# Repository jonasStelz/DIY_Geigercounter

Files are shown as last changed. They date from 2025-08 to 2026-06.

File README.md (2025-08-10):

# ESP32-S3 Geiger Counter PCB

A custom-designed **battery-powered** Geiger counter board created in **KiCad**, featuring an **ESP32-S3-WROOM-1** module, an LCD display, and a high-voltage section for driving a Geiger–Müller tube.

This project combines radiation detection with IoT capabilities, allowing live data display and wireless transmission without being tethered to a power source.

---

## Features

- **ESP32-S3-WROOM-1** microcontroller for high performance and Wi-Fi/Bluetooth connectivity  
- **LCD display** for real-time radiation readings and system status  
- Integrated **high-voltage generator** for Geiger–Müller tube operation  
- **USB-C** connector for charging and programming  
- **Battery-powered** for portable use (Li-ion/LiPo support)  
- Compact PCB layout for handheld or embedded use  
- Designed entirely in **KiCad**

---

## Hardware Overview

The PCB integrates both the high-voltage section (for the tube) and the low-voltage digital section (ESP32 + display + battery management) on the same board.  
Special care has been taken to separate HV signals from sensitive logic lines.

---

## Feedback & Contributions

This is my first PCB design combining high-voltage circuitry with an ESP32-S3 microcontroller.  
I welcome **design reviews, suggestions, and improvements** — especially regarding:  
- HV layout and safety clearances  
- EMC and noise reduction  
- Power supply stability (especially with battery use)  
- General PCB best practices  

If you spot an issue or have an idea, please open an **Issue** or submit a **Pull Request**.

---

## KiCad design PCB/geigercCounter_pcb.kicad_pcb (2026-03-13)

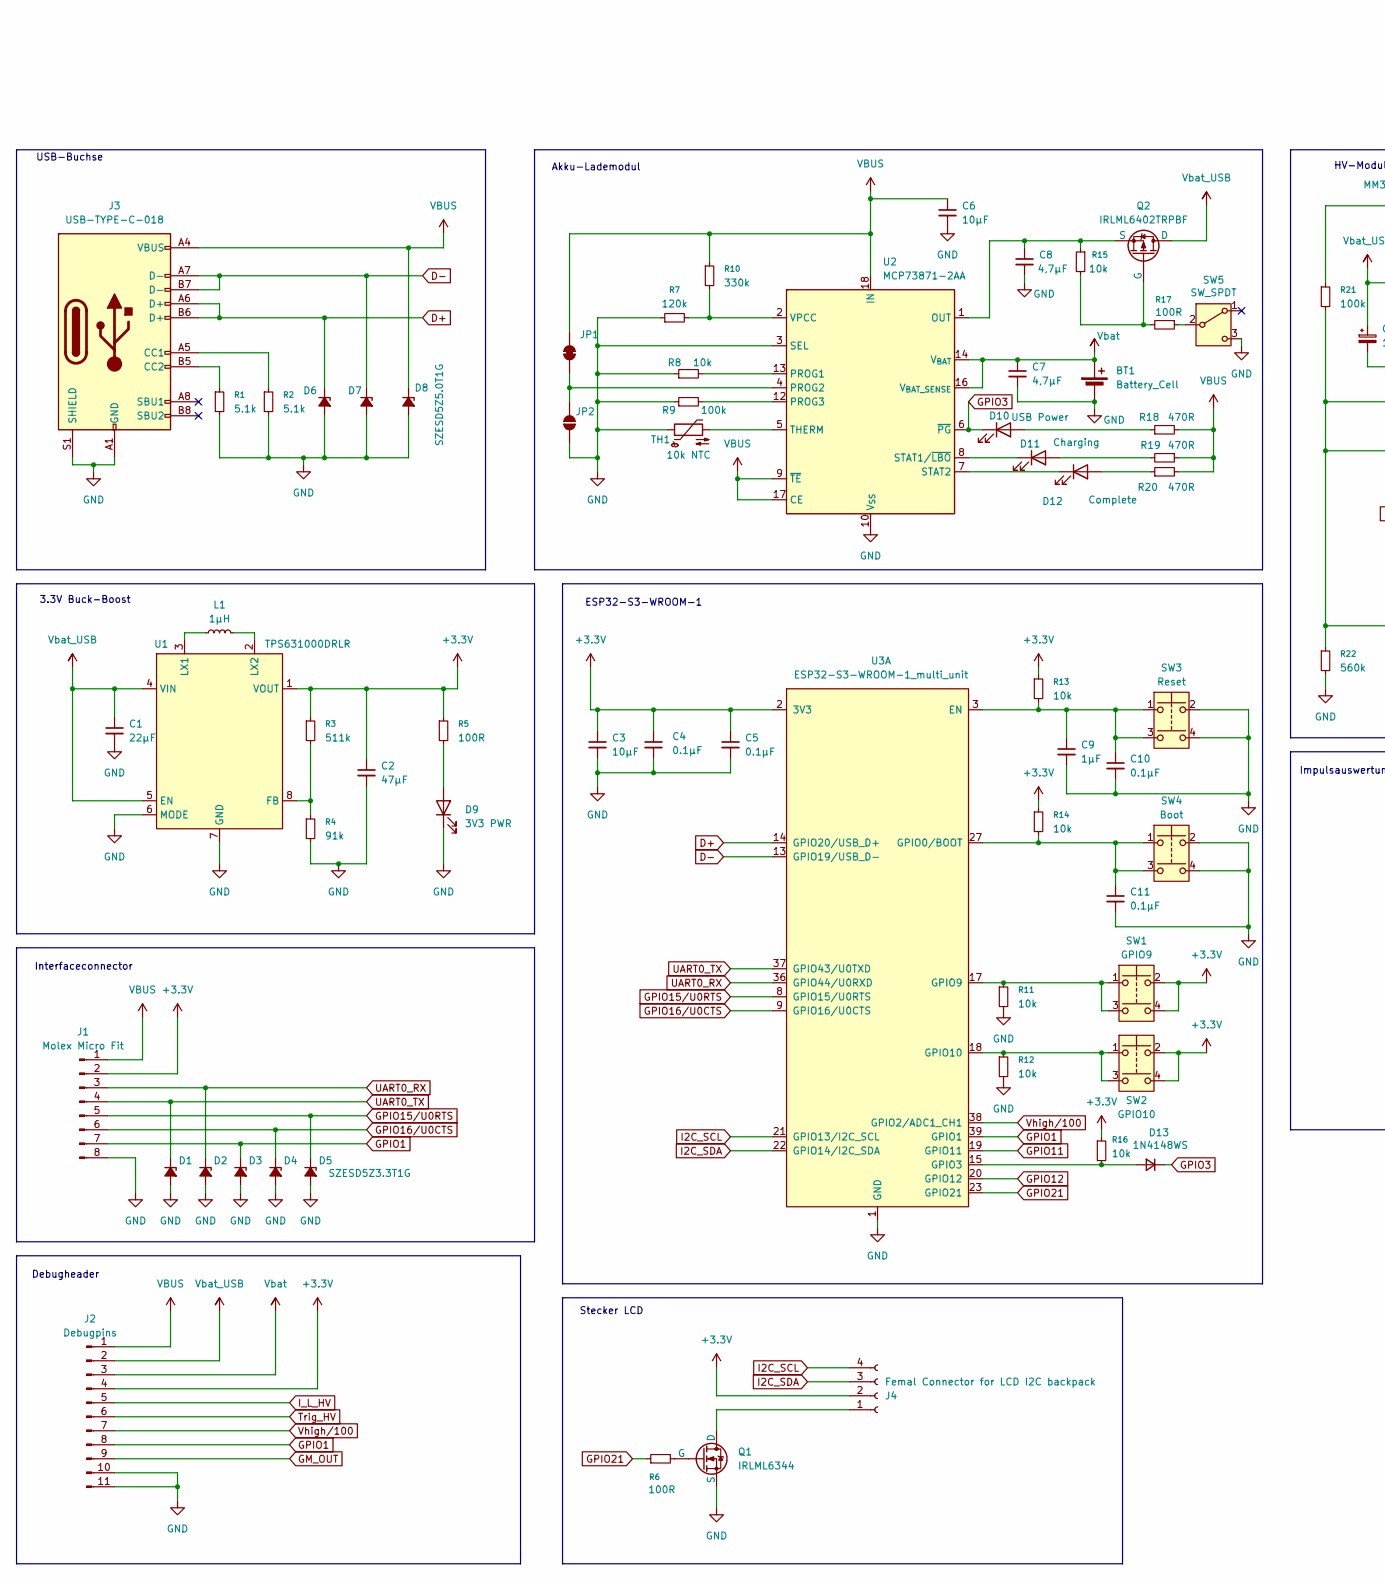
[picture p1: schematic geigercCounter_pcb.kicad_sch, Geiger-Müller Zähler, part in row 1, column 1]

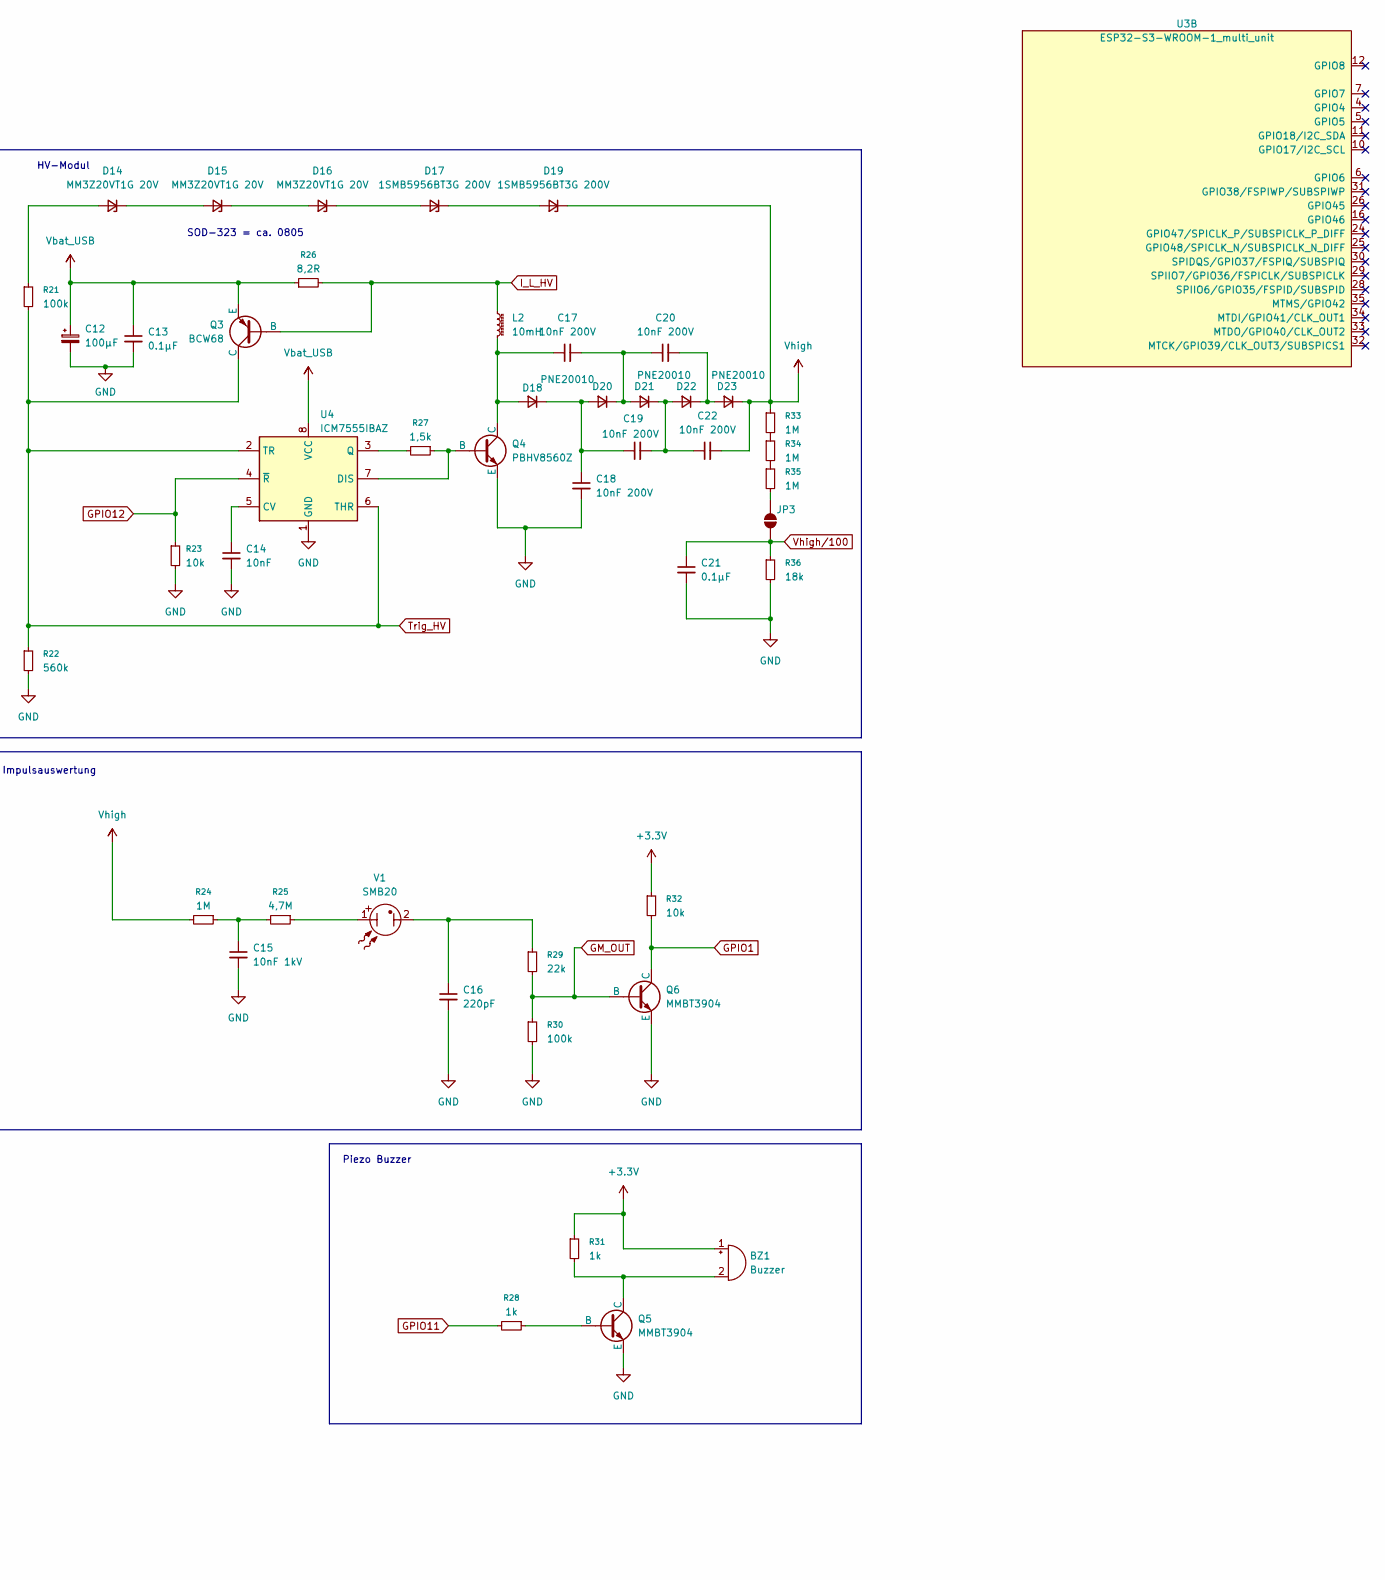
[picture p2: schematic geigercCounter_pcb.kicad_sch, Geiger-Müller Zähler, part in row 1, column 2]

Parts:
BT1: Battery_Cell; JST_PH_B2B-PH-SM4-TB_1x02-1MP_P2.00mm_Vertical
BZ1: Buzzer; CMI-9705-0380
C1: 22µF; C_0805_2012Metric_Pad1.18x1.45mm_HandSolder
C2: 47µF; C_0805_2012Metric_Pad1.18x1.45mm_HandSolder
C3, C6: 10µF; C_0805_2012Metric_Pad1.18x1.45mm_HandSolder
C4, C5, C10, C11, C13, C21: 0.1µF; C_0805_2012Metric_Pad1.18x1.45mm_HandSolder
C7, C8: 4,7µF; C_0805_2012Metric_Pad1.18x1.45mm_HandSolder
C9: 1µF; C_0805_2012Metric_Pad1.18x1.45mm_HandSolder
C12: 100µF; CP_Elec_6.3x5.9
C14: 10nF; C_0805_2012Metric_Pad1.18x1.45mm_HandSolder
C15: 10nF 1kV; C_1206_3216Metric_Pad1.33x1.80mm_HandSolder
C16: 220pF; C_0805_2012Metric_Pad1.18x1.45mm_HandSolder
C17, C18, C19, C20, C22: 10nF 200V; C_0805_2012Metric_Pad1.18x1.45mm_HandSolder
D1, D2, D3, D4, D5: SZESD5Z3.3T1G; D_SOD-523
D6, D7, D8: SZESD5Z5.0T1G; D_SOD-523
D9: 3V3 PWR; LED_0805_2012Metric_Pad1.15x1.40mm_HandSolder
D10: USB Power; LED_0805_2012Metric_Pad1.15x1.40mm_HandSolder
D11: Charging; LED_0805_2012Metric_Pad1.15x1.40mm_HandSolder
D12: Complete; LED_0805_2012Metric_Pad1.15x1.40mm_HandSolder
D13: 1N4148WS; D_SOD-323_HandSoldering
D14, D15, D16: MM3Z20VT1G 20V; D_SOD-323_HandSoldering
D17, D19: 1SMB5956BT3G 200V; D_SMB_Handsoldering
D18, D20, D21, D22, D23: PNE20010; Nexperia_CFP3_SOD-123W
J1: Molex Micro Fit; Molex_Micro-Fit_3.0_43045-0810_2x04-1MP_P3.00mm_Horizontal
J2: Debugpins; PinHeader_1x11_P2.54mm_Vertical
J3: USB-TYPE-C-018; USB_C_Receptacle_GCT_USB4105-xx-A_16P_TopMnt_Horizontal
J4: Femal Connector for LCD I2C backpack; PinHeader_1x04_P2.54mm_Horizontal
JP1: SolderJumper_2_Bridged; SolderJumper-2_P1.3mm_Open_RoundedPad1.0x1.5mm
JP2, JP3: SolderJumper_2_Open; SolderJumper-2_P1.3mm_Open_RoundedPad1.0x1.5mm
L1: 1µH; Murata_DFE252012P
L2: 10mH; Inductor_wuerth_7447709222
Q1: IRLML6344; SOT-23-3
Q2: IRLML6402TRPBF; SOT-23-3
Q3: BCW68; SOT-23-3
Q4: PBHV8560Z; SOT-223-3_TabPin2
Q5, Q6: MMBT3904; SOT-23-3
R1, R2: 5.1k; R_0805_2012Metric_Pad1.20x1.40mm_HandSolder
R3: 511k; R_0805_2012Metric_Pad1.20x1.40mm_HandSolder
R4: 91k; R_0805_2012Metric_Pad1.20x1.40mm_HandSolder
R5, R6, R17: 100R; R_0805_2012Metric_Pad1.20x1.40mm_HandSolder
R7: 120k; R_0805_2012Metric_Pad1.20x1.40mm_HandSolder
R8, R11, R12, R13, R14, R15, R16, R23, R32: 10k; R_0805_2012Metric_Pad1.20x1.40mm_HandSolder
R9, R21, R30: 100k; R_0805_2012Metric_Pad1.20x1.40mm_HandSolder
R10: 330k; R_0805_2012Metric_Pad1.20x1.40mm_HandSolder
R18, R19, R20: 470R; R_0805_2012Metric_Pad1.20x1.40mm_HandSolder
R22: 560k; R_0805_2012Metric_Pad1.20x1.40mm_HandSolder
R24, R33, R34, R35: 1M; R_0805_2012Metric_Pad1.20x1.40mm_HandSolder
R25: 4,7M; R_0805_2012Metric_Pad1.20x1.40mm_HandSolder
R26: 8,2R; R_0805_2012Metric_Pad1.20x1.40mm_HandSolder
R27: 1,5k; R_0805_2012Metric_Pad1.20x1.40mm_HandSolder
R28, R31: 1k; R_0805_2012Metric_Pad1.20x1.40mm_HandSolder
R29: 22k; R_0805_2012Metric_Pad1.20x1.40mm_HandSolder
R36: 18k; R_0805_2012Metric_Pad1.20x1.40mm_HandSolder
SW1: GPIO9; SW_Push_1P1T_NO_E-Switch_TL3301NxxxxxG
SW2: GPIO10; SW_Push_1P1T_NO_E-Switch_TL3301NxxxxxG
SW3: Reset; SW_Push_1P1T_NO_E-Switch_TL3301NxxxxxG
SW4: Boot; SW_Push_1P1T_NO_E-Switch_TL3301NxxxxxG
SW5: SW_SPDT; SW_SPDT_PCM12
TH1: 10k NTC; R_0805_2012Metric_Pad1.20x1.40mm_HandSolder
U1: TPS631000DRLR; SOT-583-8
U2: MCP73871-2AA; QFN-20-1EP_4x4mm_P0.5mm_EP2.5x2.5mm
U3: ESP32-S3-WROOM-1_multi_unit; ESP32-S3-WROOM-1
U4: ICM7555IBAZ; SOIC-8_3.9x4.9mm_P1.27mm
V1: SMB20; SBM-20

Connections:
+3.3V: BZ1.1 (+), C2.1, C3.1, C4.1, C5.1, J1.2, J2.4, J4.2, R3.1, R5.1, R13.1, R14.1, R16.1, R31.1, R32.1, SW1.2, SW1.4 (1), SW2.2, SW2.4 (2), U1.1 (VOUT), U3.2 (3V3)
D+: D6.1 (K), J3.A6 (D+), J3.B6 (D+), U3.14 (GPIO20/USB_D+)
D-: D7.1 (K), J3.A7 (D-), J3.B7 (D-), U3.13 (GPIO19/USB_D-)
GM_OUT: J2.9, Q6.1 (B), R29.2, R30.1
GND: BT1.2 (-), C1.2, C2.2, C3.2, C4.2, C5.2, C6.2, C7.2, C8.2, C9.2, C10.2, C11.2, C12.2, C13.2, C14.2, C15.2, C16.2, C18.2, C21.2, D1.2 (A), D2.2 (A), D3.2 (A), D4.2 (A), D5.2 (A), D6.2 (A), D7.2 (A), D8.2 (A), D9.1 (K), J1.8, J1.MP, J2.10, J2.11, J3.A1 (GND), J3.A12 (GND), J3.B1 (GND), J3.B12 (GND), J3.S1 (SHIELD), JP2.1 (A), Q1.2 (S), Q4.3 (E), Q5.2 (E), Q6.2 (E), R1.2, R2.2, R4.2, R7.1, R8.1, R9.1, R11.2, R12.2, R22.2, R23.2, R30.2, R36.2, SW3.2, SW3.4 (2), SW4.2, SW4.4 (1), SW5.3 (C), TH1.1, U1.6 (MODE), U1.7 (GND), U2.3 (SEL), U2.10 (V_{SS}), U2.11 (V_{SS}), U2.21 (V_{SS}), U3.1 (GND), U3.40 (GND), U3.41 (GND), U4.1 (GND)
GPIO1: D3.1 (K), J1.7, J2.8, Q6.3 (C), R32.2, U3.39 (GPIO1)
GPIO3: D10.1 (K), D13.1 (K), U2.6 (~PG)
GPIO11: R28.2, U3.19 (GPIO11)
GPIO12: R23.1, U3.20 (GPIO12), U4.4 (~R)
GPIO15/U0RTS: D5.1 (K), J1.5, U3.8 (GPIO15/U0RTS)
GPIO16/U0CTS: D4.1 (K), J1.6, U3.9 (GPIO16/U0CTS)
GPIO21: R6.1, U3.23 (GPIO21)
I2C_SCL: J4.4, U3.21 (GPIO13/I2C_SCL)
I2C_SDA: J4.3, U3.22 (GPIO14/I2C_SDA)
I_L_HV: J2.5, L2.1, Q3.1 (B), R26.2
unnamed: BZ1.2 (-), Q5.3 (C), R31.2
unnamed: C15.1, R24.1, R25.2
unnamed: C16.1, R29.1, V1.2
unnamed: D9.2 (A), R5.2
unnamed: D10.2 (A), R18.1
unnamed: D11.2 (A), R19.2
unnamed: D11.1 (K), U2.8 (STAT1/~LBO)
unnamed: D12.2 (A), R20.1
unnamed: D12.1 (K), U2.7 (STAT2)
unnamed: D13.2 (A), R16.2, U3.15 (GPIO3)
unnamed: D14.2 (A), R21.1
unnamed: D14.1 (K), D15.2 (A)
unnamed: D15.1 (K), D16.2 (A)
unnamed: D16.1 (K), D17.2 (A)
unnamed: D17.1 (K), D19.2 (A)
unnamed: C17.1, D18.2 (A), L2.2, Q4.2 (C)
unnamed: C18.1, C19.1, D18.1 (K), D20.2 (A)
unnamed: C17.2, C20.1, D20.1 (K), D21.2 (A)
unnamed: C19.2, C22.1, D21.1 (K), D22.2 (A)
unnamed: C20.2, D22.1 (K), D23.2 (A)
unnamed: J3.A5 (CC1), R2.1
unnamed: J3.B5 (CC2), R1.1
unnamed: J4.1, Q1.3 (D)
unnamed: JP1.1 (A), JP2.2 (B), U2.4 (PROG2)
unnamed: JP3.2 (B), R35.2
unnamed: Q1.1 (G), R6.2
unnamed: Q2.1 (G), R15.2, R17.2
unnamed: C8.1, Q2.2 (S), R15.1, U2.1 (OUT), U2.20 (OUT)
unnamed: Q4.1 (B), R27.1, U4.7 (DIS)
unnamed: Q5.1 (B), R28.1
unnamed: R25.1, V1.1
unnamed: R33.2, R34.1
unnamed: R34.2, R35.1
unnamed: R17.1, SW5.2 (B)
unnamed: R3.2, R4.1, U1.8 (FB)
unnamed: L1.1, U1.3 (LX1)
unnamed: L1.2, U1.2 (LX2)
unnamed: R8.2, U2.13 (PROG1)
unnamed: R9.2, U2.12 (PROG3)
unnamed: TH1.2, U2.5 (THERM)
unnamed: R7.2, R10.2, U2.2 (VPCC)
unnamed: C9.1, C10.1, R13.2, SW3.1, SW3.3 (1), U3.3 (EN)
unnamed: C11.1, R14.2, SW4.1, SW4.3 (1), U3.27 (GPIO0/BOOT)
unnamed: R11.1, SW1.1, SW1.3 (1), U3.17 (GPIO9)
unnamed: R12.1, SW2.1, SW2.3 (1), U3.18 (GPIO10)
unnamed: C14.1, U4.5 (CV)
unnamed: R27.2, U4.3 (Q)
Trig_HV: J2.6, Q3.3 (C), R21.2, R22.1, U4.2 (TR), U4.6 (THR)
UART0_RX: D2.1 (K), J1.3, U3.36 (GPIO44/U0RXD)
UART0_TX: D1.1 (K), J1.4, U3.37 (GPIO43/U0TXD)
VBUS: C6.1, D8.1 (K), J1.1, J2.1, J3.A4 (VBUS), J3.A9 (VBUS), J3.B4 (VBUS), J3.B9 (VBUS), JP1.2 (B), R10.1, R18.2, R19.1, R20.2, U2.9 (~TE), U2.17 (CE), U2.18 (IN), U2.19 (IN)
Vbat: BT1.1 (+), C7.1, J2.3, U2.14 (V_{BAT}), U2.15 (V_{BAT}), U2.16 (V_{BAT_SENSE})
Vbat_USB: C1.1, C12.1, C13.1, J2.2, Q2.3 (D), Q3.2 (E), R26.1, U1.4 (VIN), U1.5 (EN), U4.8 (VCC)
Vhigh: C22.2, D19.1 (K), D23.1 (K), R24.2, R33.1
Vhigh/100: C21.1, J2.7, JP3.1 (A), R36.1, U3.38 (GPIO2/ADC1_CH1)

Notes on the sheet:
3.3V Buck-Boost
Stecker LCD
USB-Buchse
Akku-Lademodul
ESP32-S3-WROOM-1
Impulsauswertung
SOD-323 = ca. 0805
HV-Modul
Interfaceconnector
Piezo Buzzer
Debugheader

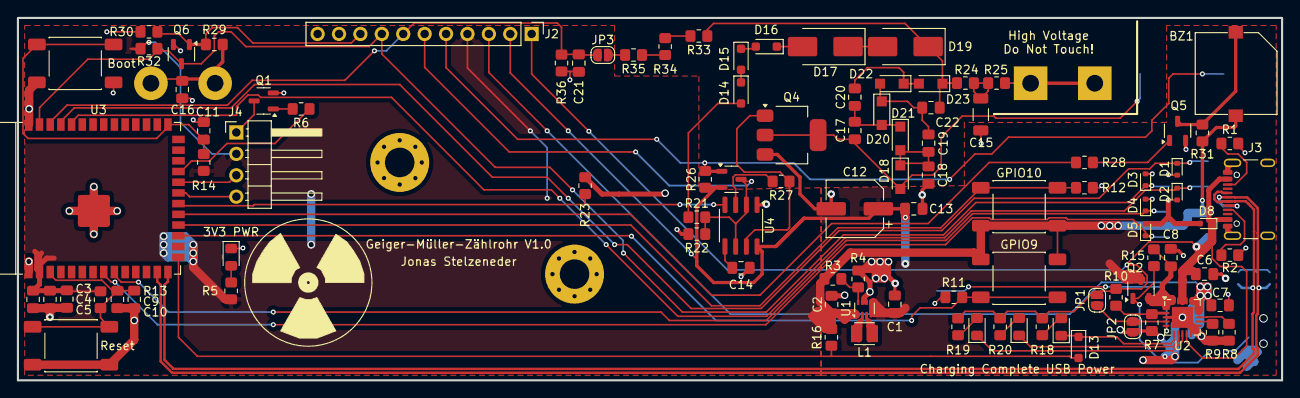
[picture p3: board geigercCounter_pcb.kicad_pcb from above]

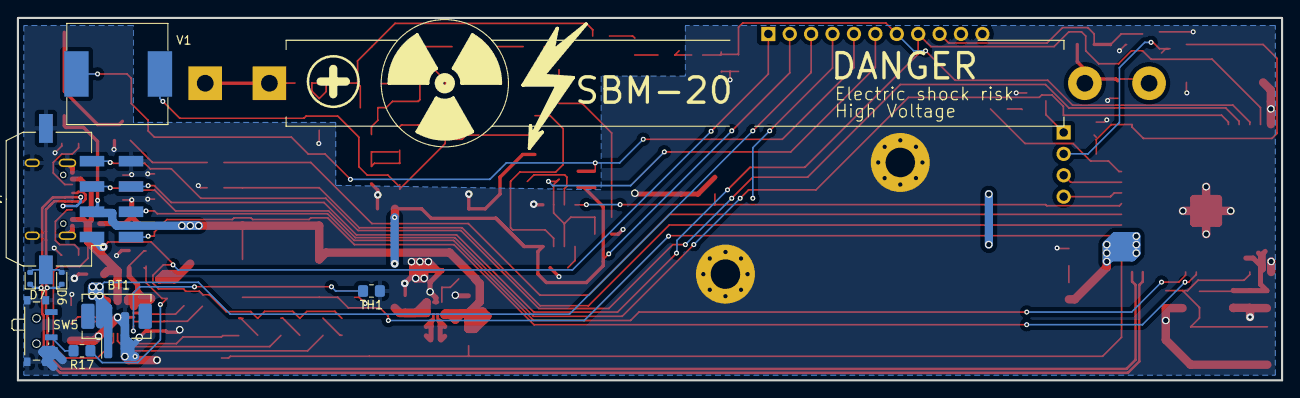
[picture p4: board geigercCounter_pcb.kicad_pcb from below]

Board: 2 copper layers, 150.0 x 43.0 mm, 109 parts (9 on the bottom side), 70 nets.

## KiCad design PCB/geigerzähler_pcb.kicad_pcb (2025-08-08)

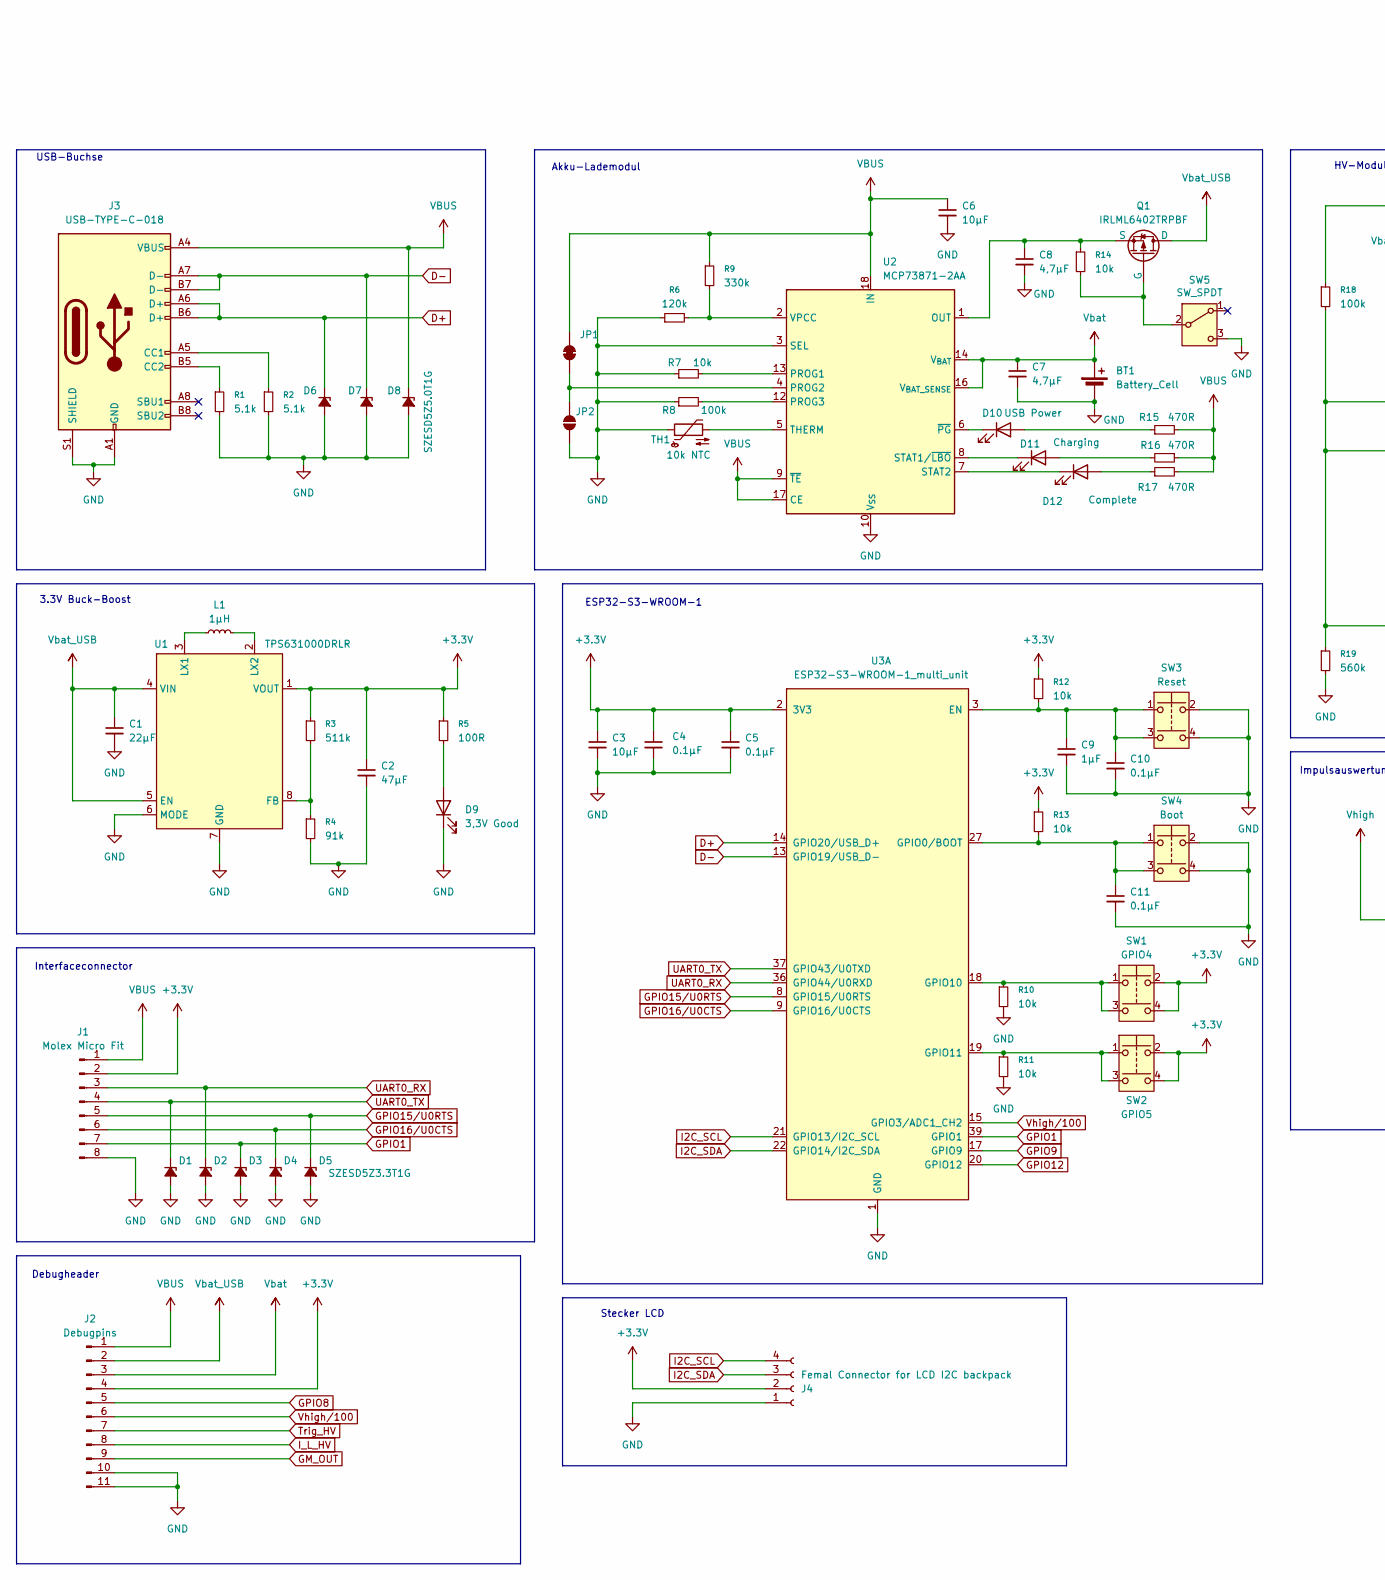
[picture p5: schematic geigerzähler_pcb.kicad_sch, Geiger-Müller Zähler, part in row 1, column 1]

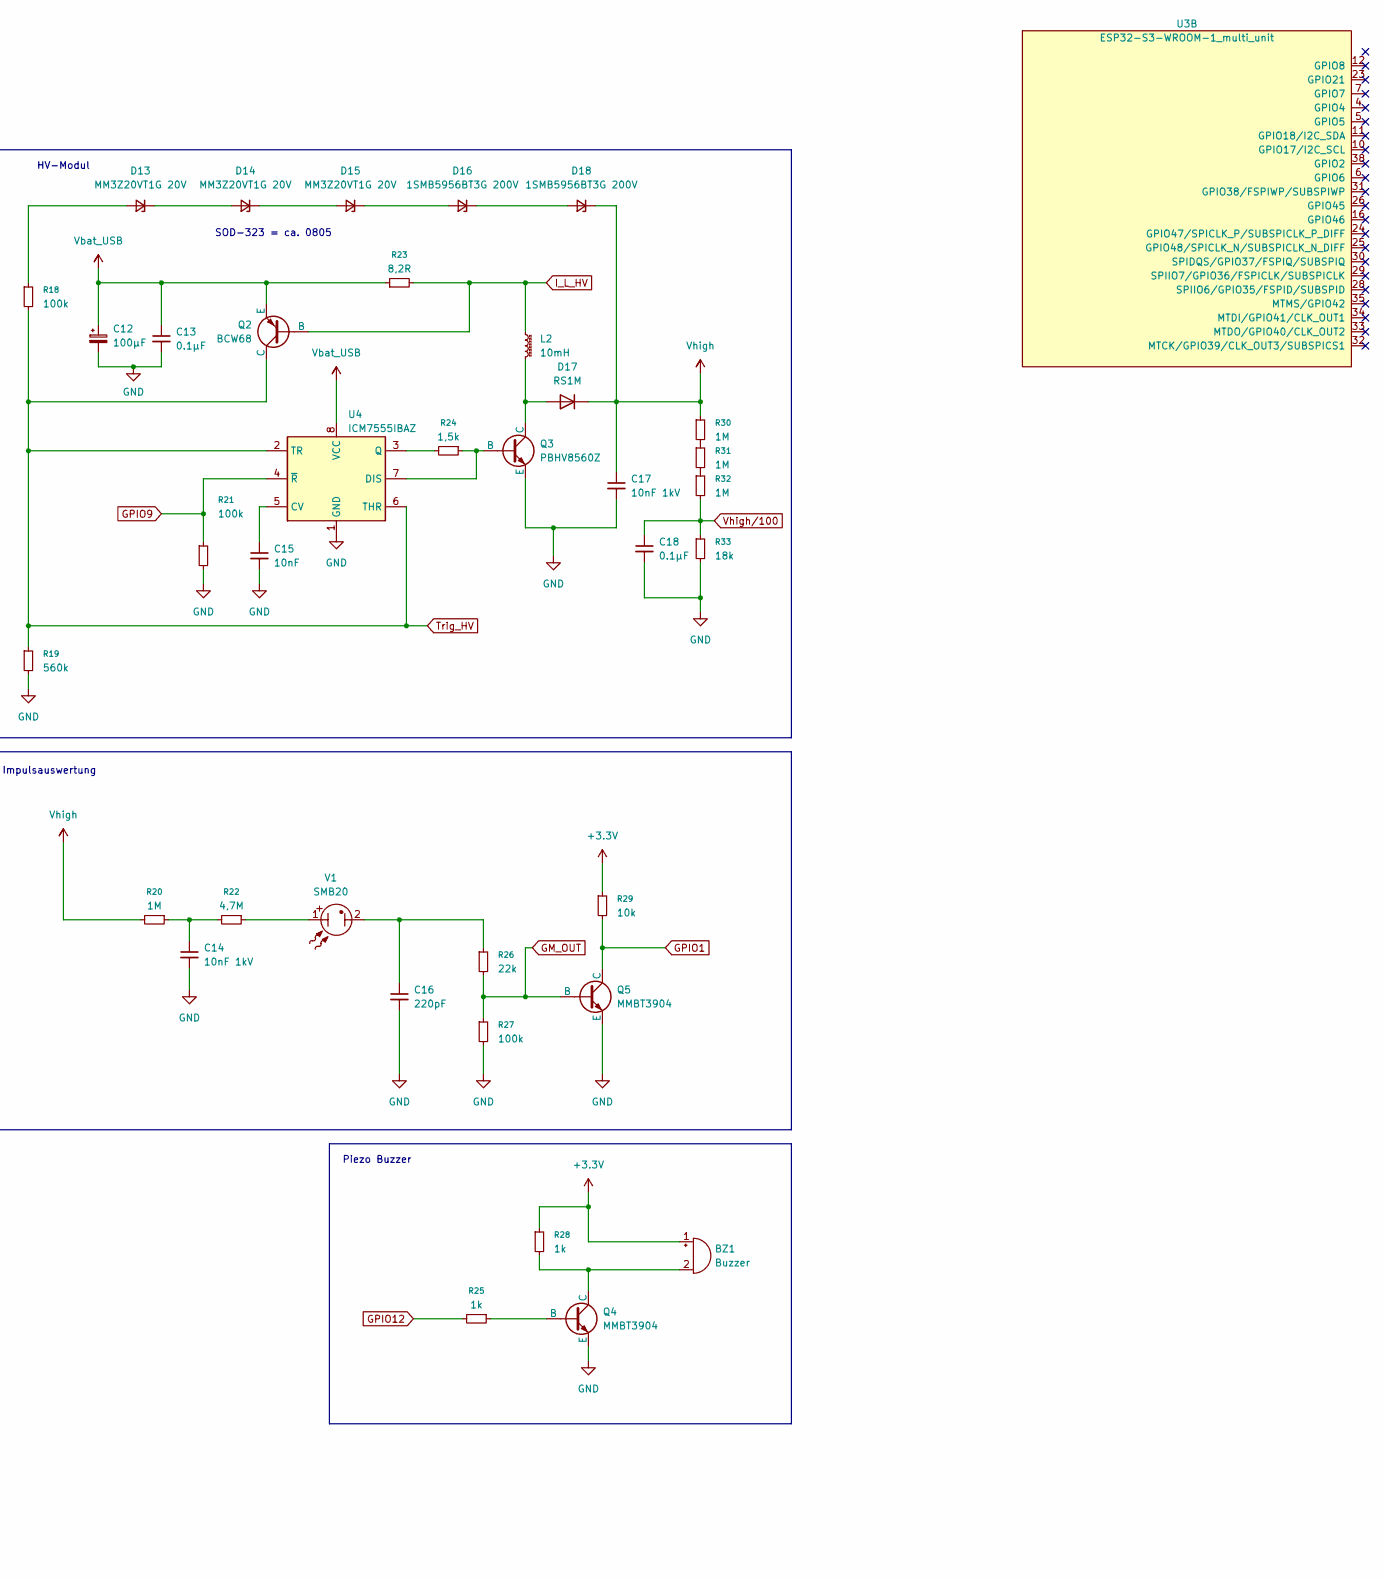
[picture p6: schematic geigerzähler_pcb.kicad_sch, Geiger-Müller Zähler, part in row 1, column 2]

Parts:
BT1: Battery_Cell; JST_PH_B2B-PH-SM4-TB_1x02-1MP_P2.00mm_Vertical
BZ1: Buzzer; CMI-9705-0380
C1: 22µF; C_0805_2012Metric_Pad1.18x1.45mm_HandSolder
C2: 47µF; C_0805_2012Metric_Pad1.18x1.45mm_HandSolder
C3, C6: 10µF; C_0805_2012Metric_Pad1.18x1.45mm_HandSolder
C4, C5, C10, C11, C13, C18: 0.1µF; C_0805_2012Metric_Pad1.18x1.45mm_HandSolder
C7, C8: 4,7µF; C_0805_2012Metric_Pad1.18x1.45mm_HandSolder
C9: 1µF; C_0805_2012Metric_Pad1.18x1.45mm_HandSolder
C12: 100µF; CP_Elec_6.3x5.9
C14, C17: 10nF 1kV; C_1206_3216Metric_Pad1.33x1.80mm_HandSolder
C15: 10nF; C_0805_2012Metric_Pad1.18x1.45mm_HandSolder
C16: 220pF; C_0805_2012Metric_Pad1.18x1.45mm_HandSolder
D1, D2, D3, D4, D5: SZESD5Z3.3T1G; D_SOD-523
D6, D7, D8: SZESD5Z5.0T1G; D_SOD-523
D9: 3,3V Good; LED_0805_2012Metric_Pad1.15x1.40mm_HandSolder
D10: USB Power; LED_0805_2012Metric_Pad1.15x1.40mm_HandSolder
D11: Charging; LED_0805_2012Metric_Pad1.15x1.40mm_HandSolder
D12: Complete; LED_0805_2012Metric_Pad1.15x1.40mm_HandSolder
D13, D14, D15: MM3Z20VT1G 20V; D_SOD-323_HandSoldering
D16, D18: 1SMB5956BT3G 200V; D_SMB_Handsoldering
D17: RS1M; D_SMA
J1: Molex Micro Fit; Molex_Micro-Fit_3.0_43045-0810_2x04-1MP_P3.00mm_Horizontal
J2: Debugpins; PinHeader_1x11_P2.54mm_Vertical
J3: USB-TYPE-C-018; USB_C_Receptacle_GCT_USB4105-xx-A_16P_TopMnt_Horizontal
J4: Femal Connector for LCD I2C backpack; PinHeader_1x04_P2.54mm_Horizontal
JP1: SolderJumper_2_Bridged; SolderJumper-2_P1.3mm_Open_RoundedPad1.0x1.5mm
JP2: SolderJumper_2_Open; SolderJumper-2_P1.3mm_Open_RoundedPad1.0x1.5mm
L1: 1µH; Murata_DFE252012P
L2: 10mH; Inductor_wuerth_74404086103
Q1: IRLML6402TRPBF; SOT-23-3
Q2: BCW68; SOT-23-3
Q3: PBHV8560Z; SOT-223-3_TabPin2
Q4, Q5: MMBT3904; SOT-23-3
R1, R2: 5.1k; R_0805_2012Metric_Pad1.20x1.40mm_HandSolder
R3: 511k; R_0805_2012Metric_Pad1.20x1.40mm_HandSolder
R4: 91k; R_0805_2012Metric_Pad1.20x1.40mm_HandSolder
R5: 100R; R_0805_2012Metric_Pad1.20x1.40mm_HandSolder
R6: 120k; R_0805_2012Metric_Pad1.20x1.40mm_HandSolder
R7, R10, R11, R12, R13, R14, R29: 10k; R_0805_2012Metric_Pad1.20x1.40mm_HandSolder
R8, R18, R21, R27: 100k; R_0805_2012Metric_Pad1.20x1.40mm_HandSolder
R9: 330k; R_0805_2012Metric_Pad1.20x1.40mm_HandSolder
R15, R16, R17: 470R; R_0805_2012Metric_Pad1.20x1.40mm_HandSolder
R19: 560k; R_0805_2012Metric_Pad1.20x1.40mm_HandSolder
R20, R30, R31, R32: 1M; R_0805_2012Metric_Pad1.20x1.40mm_HandSolder
R22: 4,7M; R_0805_2012Metric_Pad1.20x1.40mm_HandSolder
R23: 8,2R; R_0805_2012Metric_Pad1.20x1.40mm_HandSolder
R24: 1,5k; R_0805_2012Metric_Pad1.20x1.40mm_HandSolder
R25, R28: 1k; R_0805_2012Metric_Pad1.20x1.40mm_HandSolder
R26: 22k; R_0805_2012Metric_Pad1.20x1.40mm_HandSolder
R33: 18k; R_0805_2012Metric_Pad1.20x1.40mm_HandSolder
SW1: GPIO4; SW_Push_1P1T_NO_E-Switch_TL3301NxxxxxG
SW2: GPIO5; SW_Push_1P1T_NO_E-Switch_TL3301NxxxxxG
SW3: Reset; SW_Push_1P1T_NO_E-Switch_TL3301NxxxxxG
SW4: Boot; SW_Push_1P1T_NO_E-Switch_TL3301NxxxxxG
SW5: SW_SPDT; SW_SPDT_PCM12
TH1: 10k NTC; R_0805_2012Metric_Pad1.20x1.40mm_HandSolder
U1: TPS631000DRLR; SOT-583-8
U2: MCP73871-2AA; QFN-20-1EP_4x4mm_P0.5mm_EP2.5x2.5mm
U3: ESP32-S3-WROOM-1_multi_unit; ESP32-S3-WROOM-1
U4: ICM7555IBAZ; SOIC-8_3.9x4.9mm_P1.27mm
V1: SMB20; SBM-20

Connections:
+3.3V: BZ1.1 (+), C2.1, C3.1, C4.1, C5.1, J1.2, J2.4, J4.2, R3.1, R5.1, R12.1, R13.1, R28.1, R29.1, SW1.2, SW1.4 (1), SW2.2, SW2.4 (2), U1.1 (VOUT), U3.2 (3V3)
D+: D6.1 (K), J3.A6 (D+), J3.B6 (D+), U3.14 (GPIO20/USB_D+)
D-: D7.1 (K), J3.A7 (D-), J3.B7 (D-), U3.13 (GPIO19/USB_D-)
GM_OUT: J2.9, Q5.1 (B), R26.2, R27.1
GPIO1: D3.1 (K), J1.7, Q5.3 (C), R29.2, U3.39 (GPIO1)
GPIO8: J2.5
GPIO9: R21.1, U3.17 (GPIO9), U4.4 (~R)
GPIO12: R25.2, U3.20 (GPIO12)
GPIO15/U0RTS: D5.1 (K), J1.5, U3.8 (GPIO15/U0RTS)
GPIO16/U0CTS: D4.1 (K), J1.6, U3.9 (GPIO16/U0CTS)
I2C_SCL: J4.4, U3.21 (GPIO13/I2C_SCL)
I2C_SDA: J4.3, U3.22 (GPIO14/I2C_SDA)
I_L_HV: J2.8, L2.1, Q2.1 (B), R23.2
unnamed: BZ1.2 (-), Q4.3 (C), R28.2
unnamed: C14.1, R20.1, R22.2
unnamed: C16.1, R26.1, V1.2
unnamed: D9.2 (A), R5.2
unnamed: D10.2 (A), R15.1
unnamed: D10.1 (K), U2.6 (~PG)
unnamed: D11.2 (A), R16.2
unnamed: D11.1 (K), U2.8 (STAT1/~LBO)
unnamed: D12.2 (A), R17.1
unnamed: D12.1 (K), U2.7 (STAT2)
unnamed: D13.2 (A), R18.1
unnamed: D13.1 (K), D14.2 (A)
unnamed: D14.1 (K), D15.2 (A)
unnamed: D15.1 (K), D16.2 (A)
unnamed: D16.1 (K), D18.2 (A)
unnamed: D17.2 (A), L2.2, Q3.2 (C)
unnamed: J3.A5 (CC1), R2.1
unnamed: J3.B5 (CC2), R1.1
unnamed: JP1.1 (A), JP2.2 (B), U2.4 (PROG2)
unnamed: Q1.2 (G), R14.2, SW5.2 (B)
unnamed: C8.1, Q1.3 (S), R14.1, U2.1 (OUT), U2.20 (OUT)
unnamed: Q3.1 (B), R24.1, U4.7 (DIS)
unnamed: Q4.1 (B), R25.1
unnamed: R22.1, V1.1
unnamed: R30.2, R31.1
unnamed: R31.2, R32.1
unnamed: R3.2, R4.1, U1.8 (FB)
unnamed: L1.1, U1.3 (LX1)
unnamed: L1.2, U1.2 (LX2)
unnamed: R7.2, U2.13 (PROG1)
unnamed: R8.2, U2.12 (PROG3)
unnamed: TH1.2, U2.5 (THERM)
unnamed: R6.2, R9.2, U2.2 (VPCC)
unnamed: C9.1, C10.1, R12.2, SW3.1, SW3.3 (1), U3.3 (EN)
unnamed: C11.1, R13.2, SW4.1, SW4.3 (1), U3.27 (GPIO0/BOOT)
unnamed: R10.1, SW1.1, SW1.3 (1), U3.18 (GPIO10)
unnamed: R11.1, SW2.1, SW2.3 (1), U3.19 (GPIO11)
unnamed: C15.1, U4.5 (CV)
unnamed: R24.2, U4.3 (Q)
Trig_HV: J2.7, Q2.3 (C), R18.2, R19.1, U4.2 (TR), U4.6 (THR)
UART0_RX: D2.1 (K), J1.3, U3.36 (GPIO44/U0RXD)
UART0_TX: D1.1 (K), J1.4, U3.37 (GPIO43/U0TXD)
Vbat: BT1.1 (+), C7.1, J2.3, U2.14 (V_{BAT}), U2.15 (V_{BAT}), U2.16 (V_{BAT_SENSE})
Vbat_USB: C1.1, C12.1, C13.1, J2.2, Q1.1 (D), Q2.2 (E), R23.1, U1.4 (VIN), U1.5 (EN), U4.8 (VCC)
Vhigh: C17.1, D17.1 (K), D18.1 (K), R20.2, R30.1

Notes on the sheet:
3.3V Buck-Boost
Stecker LCD
USB-Buchse
Akku-Lademodul
ESP32-S3-WROOM-1
Impulsauswertung
SOD-323 = ca. 0805
HV-Modul
Interfaceconnector
Piezo Buzzer
Debugheader

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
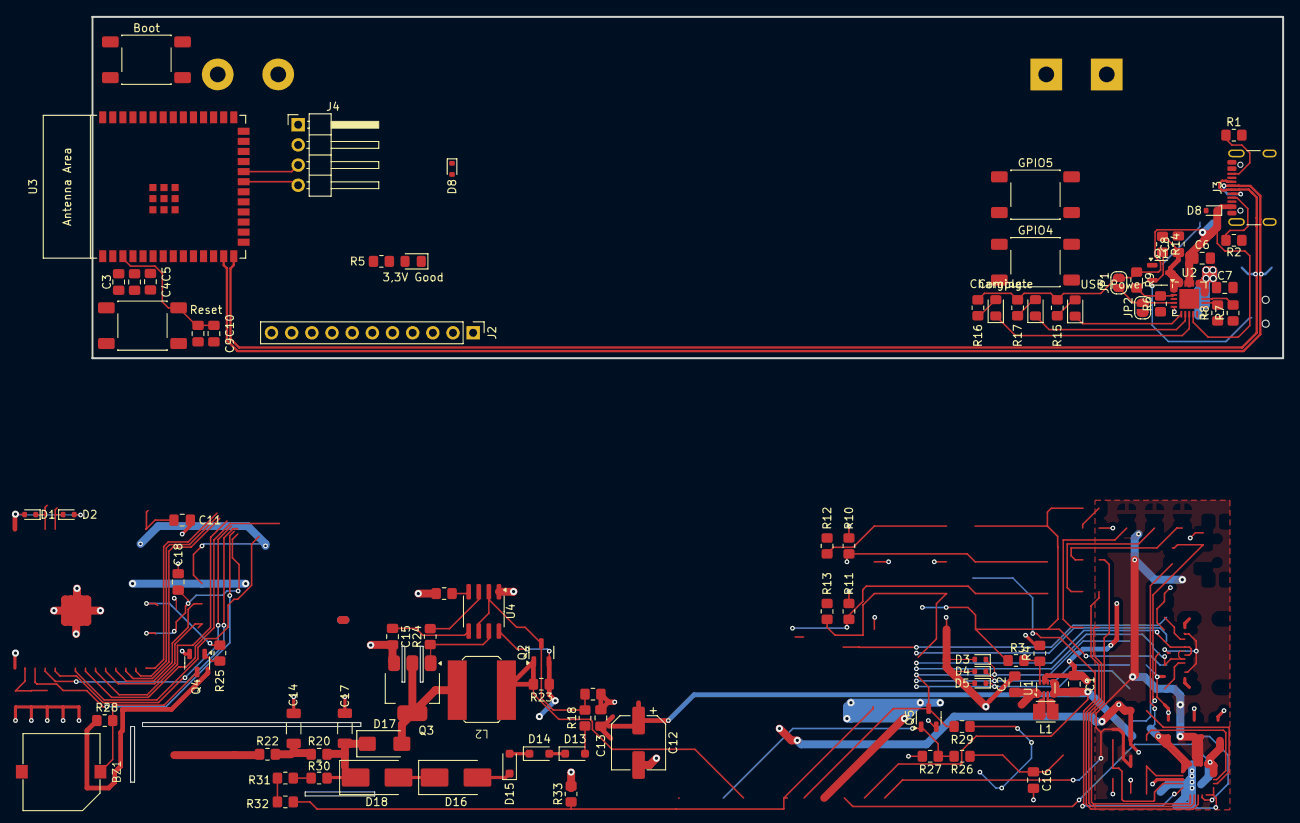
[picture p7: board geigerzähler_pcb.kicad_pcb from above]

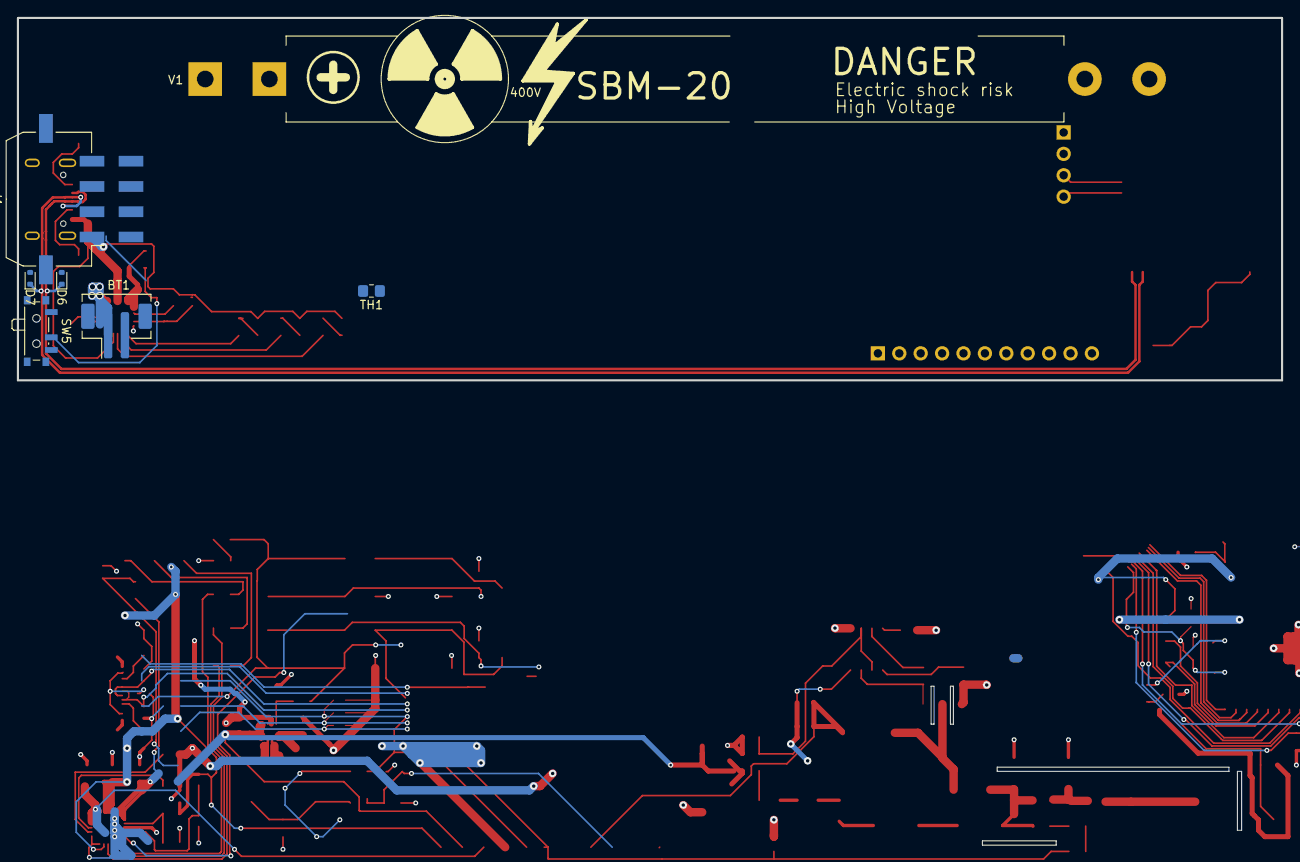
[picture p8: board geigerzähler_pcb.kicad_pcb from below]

Board: 2 copper layers, 150.0 x 98.2 mm, 96 parts (7 on the bottom side), 60 nets.

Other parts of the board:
D8#2: SZESD5Z5.0T1G; D_SOD-523

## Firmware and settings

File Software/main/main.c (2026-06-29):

#include "freertos/FreeRTOS.h"
#include "freertos/task.h"
#include "esp_log.h"
#include "driver/gpio.h"

#include "app_events.h"
#include "geiger_core.h"
#include "button_handler.h"
#include "lcd_hd44780.h"
#include "ui_menu.h"
#include "buzzer.h"
#include "hv_control.h"
#include "geiger_config.h"

static const char *TAG = "MAIN";

void app_main(void)
{
    /*
     * Early GPIO output initialisation – define safe states before any
     * component runs.  After reset all GPIOs default to input/high-Z;
     * output pins must be driven explicitly to avoid undefined hardware
     * states during the boot sequence.
     *
     *   GPIO_HV_ENABLE  (GPIO12) LOW  – ICM7555 oscillator off.
     *                                   Without this, the HV supply has an
     *                                   undefined state until hv_control_init()
     *                                   runs in Step 7.
     *
     *   GPIO_LCD_POWER  (GPIO21) LOW  – Q1 low-side MOSFET gate at 0 V.
     *                                   Prevents the MOSFET from partially
     *                                   conducting while the LCD is still
     *                                   unpowered during boot.
     *                                   lcd_init() drives it HIGH when ready.
     *
     *   GPIO_BUZZER     (GPIO11) LOW  – Piezo NPN transistor base at 0 V.
     *                                   Prevents spurious clicks before
     *                                   buzzer_init() runs in Step 8.
     */
    const gpio_config_t early_out_cfg = {
        .pin_bit_mask = (1ULL << GPIO_HV_ENABLE)
                      | (1ULL << GPIO_LCD_POWER)
                      | (1ULL << GPIO_BUZZER),
        .mode         = GPIO_MODE_OUTPUT,
        .pull_up_en   = GPIO_PULLUP_DISABLE,
        .pull_down_en = GPIO_PULLDOWN_DISABLE,
        .intr_type    = GPIO_INTR_DISABLE,
    };
    ESP_ERROR_CHECK(gpio_config(&early_out_cfg));
    gpio_set_level(GPIO_HV_ENABLE, 0);
    gpio_set_level(GPIO_LCD_POWER, 0);
    gpio_set_level(GPIO_BUZZER,    0);

    ESP_LOGI(TAG, "Geiger Counter starting");

    /* Central event loop – must be first. */
    ESP_ERROR_CHECK(app_events_init());

    /* Step 3: Geiger core (pulse counter + statistics). */
    ESP_ERROR_CHECK(geiger_core_init());
    xTaskCreate(geiger_core_task, "geiger_core",
                TASK_STACK_GEIGER_CORE, NULL, TASK_PRIO_GEIGER_CORE, NULL);

    /* Step 4: Button handler. */
    ESP_ERROR_CHECK(button_handler_init());
    xTaskCreate(button_handler_task, "btn_task",
                TASK_STACK_BUTTON, NULL, TASK_PRIO_BUTTON, NULL);

    /* Step 5: LCD driver. */
    ESP_ERROR_CHECK(lcd_init());

    /* Step 5: Buzzer. */
    ESP_ERROR_CHECK(buzzer_init());
    xTaskCreate(buzzer_task, "buzzer_task",
                TASK_STACK_BUZZER, NULL, TASK_PRIO_BUZZER, NULL);

    /* Step 6: Menu system. */
    ESP_ERROR_CHECK(ui_menu_init());
    xTaskCreate(ui_menu_task, "ui_task",
                TASK_STACK_UI, NULL, TASK_PRIO_UI, NULL);

    /* Step 7: High voltage control. */
    ESP_ERROR_CHECK(hv_control_init());
    xTaskCreate(hv_control_task, "hv_task",
                TASK_STACK_HV_CONTROL, NULL, TASK_PRIO_HV_CONTROL, NULL);

    /* Further initialisation added in Steps 7–10. */
    while (1) {
        vTaskDelay(pdMS_TO_TICKS(1000));
    }
}

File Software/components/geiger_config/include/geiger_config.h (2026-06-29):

#pragma once

/*
 * geiger_config.h – Project-wide hardware constants.
 *
 * Rules:
 *   - Plain integer / float literals ONLY.
 *   - No #include directives (dependency-free by design).
 *   - No ESP-IDF enum types (use raw values with comments).
 *   - No magic numbers anywhere else in the firmware.
 */

/* ============================================================
 * GPIO Assignments
 * ============================================================ */
#define GPIO_GEIGER_PULSE       1   /* Pulse input  – active LOW, falling edge, open-collector */
#define GPIO_BUZZER             11  /* Passive piezo via NPN transistor – HIGH = active          */
#define GPIO_HV_ENABLE          12  /* ICM7555 oscillator enable         – HIGH = HV ON          */
#define GPIO_LCD_POWER          21  /* LCD ground-path MOSFET (low-side) – HIGH = LCD on         */
#define GPIO_SW1_MENU           9   /* Menu button   – active HIGH, external pull-down            */
#define GPIO_SW2_SELECT         10  /* Select button – active HIGH, external pull-down            */
#define GPIO_I2C_SCL            13
#define GPIO_I2C_SDA            14
#define GPIO_HV_ADC             2   /* ADC1_CH1: HV feedback voltage                            */
#define GPIO_USB_STATUS         3   /* USB power present – HIGH = USB connected                 */

/* ============================================================
 * I2C / LCD (HD44780 + PCF8574 backpack)
 * ============================================================ */
#define I2C_MASTER_BUS_NUM      0           /* I2C_NUM_0        */
#define I2C_MASTER_FREQ_HZ      100000
#define LCD_I2C_ADDR            0x27
#define LCD_BACKLIGHT_BIT       0x08
#define LCD_ENABLE_BIT          0x04
#define LCD_RW_BIT              0x02
#define LCD_RS_BIT              0x01
#define LCD_COLS                16
#define LCD_ROWS                2
#define LCD_POWER_STABILIZE_MS  50          /* Wait after GPIO_LCD_POWER → HIGH before I2C access */

/* ============================================================
 * High Voltage Control (ICM7555 / SBM-20)
 * ============================================================
 * Resistor network: R33 = R34 = R35 = 1 MΩ,  R36 = 18 kΩ
 * Vadc × HV_ADC_DIVIDER_RATIO = Vhigh
 * (Using 100 would be wrong – large measurement error.)
 * ============================================================ */
#define HV_ADC_DIVIDER_RATIO    167.7f
#define HV_TARGET_VOLTAGE_V     400.0f
#define HV_HYSTERESIS_V         5.0f
#define HV_ADC_CHANNEL_NUM      1           /* ADC1_CHANNEL_1 (GPIO2) */
#define HV_REGULATION_PERIOD_MS 100         /* Regulation loop period – 10 Hz */

/* ============================================================
 * Buzzer / LEDC PWM
 * ============================================================ */
#define BUZZER_FREQ_HZ          750
#define BUZZER_DUTY_RES_BITS    13          /* LEDC_TIMER_13_BIT */
#define BUZZER_DUTY_50_PCT      4096        /* (1 << 13) / 2     */
#define BUZZER_CLICK_MS         10
#define BUZZER_LEDC_TIMER_NUM   0           /* LEDC_TIMER_0      */
#define BUZZER_LEDC_CHANNEL_NUM 0           /* LEDC_CHANNEL_0    */

/* ============================================================
 * PCNT Pulse Counter
 * ============================================================ */
#define PCNT_HIGH_LIMIT         32767
#define PCNT_LOW_LIMIT          (-1)    /* Must be < 0; we never count negative */
#define PCNT_GLITCH_FILTER_NS   1000

/* ============================================================
 * Geiger Tube Calibration
 * ============================================================ */
#define GEIGER_TUBE_CPM_PER_USVH    22.0f  /* SBM-20 nominal – change only this for a different tube */

/* ============================================================
 * CPM / Dose Rate
 * ============================================================ */
#define CPM_RING_BUFFER_SIZE    60          /* seconds – rolling window length */
#define GEIGER_CORE_TICK_MS     1000        /* geiger_core_task period         */
#define DOSE_EMA_ALPHA          0.1f        /* EMA smoothing (0 = slow, 1 = instant) */

/* ============================================================
 * LCD Timeout
 * ============================================================ */
#define LCD_TIMEOUT_S           30

/* ============================================================
 * Button Timing
 * ============================================================ */
#define BUTTON_DEBOUNCE_MS      50
#define BUTTON_LONG_PRESS_MS    400

/* ============================================================
 * NVS Persistence
 * ============================================================ */
#define NVS_NAMESPACE               "geiger"
#define NVS_SYNC_INTERVAL_COUNTS    100
#define NVS_SYNC_INTERVAL_S         300
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

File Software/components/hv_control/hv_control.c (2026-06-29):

/*
 * hv_control.c  –  HV generator control for the ICM7555-based HV supply.
 *
 * Current mode: GPIO12 HIGH = HV on, hardware handles voltage regulation.
 *
 * GPIO12 → ICM7555 oscillator enable
 *   HIGH = oscillator running = HV output active
 *   LOW  = oscillator stopped = HV output off
 *
 * ── Software regulation (disabled) ───────────────────────────────────────
 * The ADC feedback path and hysteresis regulator below are kept for
 * reference but commented out.  Re-enable if software regulation is needed:
 *
 *   GPIO2 / ADC1_CH1 → feedback divider mid-point
 *     R33=R34=R35=1MΩ, R36=18kΩ  →  Vhigh = Vadc × 167.7
 *
 *   Regulation logic:
 *     Vhigh < (target − hysteresis)  →  enable oscillator
 *     Vhigh > (target + hysteresis)  →  disable oscillator
 *     inside dead band               →  no change
 * ─────────────────────────────────────────────────────────────────────────
 */

#include "freertos/FreeRTOS.h"
#include "freertos/task.h"
/* #include "freertos/semphr.h" */       /* needed for software regulation */

#include "driver/gpio.h"
#include "esp_log.h"

/* ── ADC includes (software regulation only) ──────────────────────────── */
/* #include "esp_adc/adc_oneshot.h"    */
/* #include "esp_adc/adc_cali.h"       */
/* #include "esp_adc/adc_cali_scheme.h"*/

#include "geiger_config.h"
#include "hv_control.h"

static const char *TAG = "HV";

/* ── Internal state ───────────────────────────────────────────────────── */

/* static adc_oneshot_unit_handle_t s_adc_handle   = NULL; */
/* static adc_cali_handle_t         s_cali_handle  = NULL; */
/* static bool                      s_cali_enabled = false; */
/* static SemaphoreHandle_t         s_mutex        = NULL; */
/* static float                     s_voltage      = 0.0f; */

/* ── GPIO control ──────────────────────────────────────────────────────── */

void hv_control_enable(void)
{
    gpio_set_level(GPIO_HV_ENABLE, 1);
    ESP_LOGI(TAG, "HV ON");
}

void hv_control_disable(void)
{
    gpio_set_level(GPIO_HV_ENABLE, 0);
    ESP_LOGI(TAG, "HV OFF");
}

/* ── ADC + calibration init (software regulation only) ───────────────── */
/*
static esp_err_t adc_init(void)
{
    adc_oneshot_unit_init_cfg_t unit_cfg = {
        .unit_id  = ADC_UNIT_1,
        .ulp_mode = ADC_ULP_MODE_DISABLE,
    };
    esp_err_t ret = adc_oneshot_new_unit(&unit_cfg, &s_adc_handle);
    if (ret != ESP_OK) {
        ESP_LOGE(TAG, "adc_oneshot_new_unit: %s", esp_err_to_name(ret));
        return ret;
    }

    adc_oneshot_chan_cfg_t chan_cfg = {
        .bitwidth = ADC_BITWIDTH_DEFAULT,
        .atten    = ADC_ATTEN_DB_12,    // 0–3.1 V range; Vadc_max ≈ 2.39 V at 400 V HV
    };
    ret = adc_oneshot_config_channel(s_adc_handle,
                                     (adc_channel_t)HV_ADC_CHANNEL_NUM,
                                     &chan_cfg);
    if (ret != ESP_OK) {
        ESP_LOGE(TAG, "adc_oneshot_config_channel: %s", esp_err_to_name(ret));
        return ret;
    }

    adc_cali_line_fitting_config_t cali_cfg = {
        .unit_id  = ADC_UNIT_1,
        .atten    = ADC_ATTEN_DB_12,
        .bitwidth = ADC_BITWIDTH_DEFAULT,
    };
    ret = adc_cali_create_scheme_line_fitting(&cali_cfg, &s_cali_handle);
    if (ret == ESP_OK) {
        s_cali_enabled = true;
        ESP_LOGI(TAG, "ADC calibration enabled");
    } else {
        ESP_LOGW(TAG, "ADC calibration unavailable – using raw conversion");
        s_cali_enabled = false;
    }

    return ESP_OK;
}
*/

/* ── ADC read + Vhigh conversion (software regulation only) ──────────── */
/*
#define HV_ADC_SAMPLES 4

static float adc_read_vhigh(void)
{
    int32_t raw_sum = 0;
    for (int i = 0; i < HV_ADC_SAMPLES; i++) {
        int raw = 0;
        adc_oneshot_read(s_adc_handle, (adc_channel_t)HV_ADC_CHANNEL_NUM, &raw);
        raw_sum += raw;
    }
    int raw_avg = (int)(raw_sum / HV_ADC_SAMPLES);

    int mv = 0;
    if (s_cali_enabled) {
        adc_cali_raw_to_voltage(s_cali_handle, raw_avg, &mv);
    } else {
        mv = (raw_avg * 3100) / 4095;   // 12-bit, ~3100 mV full-scale at ATTEN_DB_12
    }

    float vadc  = mv / 1000.0f;
    float vhigh = vadc * HV_ADC_DIVIDER_RATIO;

    ESP_LOGD(TAG, "raw=%d  vadc=%.3fV  vhigh=%.1fV", raw_avg, vadc, vhigh);
    return vhigh;
}
*/

/* ── Public API ───────────────────────────────────────────────────────── */

esp_err_t hv_control_init(void)
{
    /*
     * GPIO12 is already configured as OUTPUT LOW by the early GPIO init
     * block in app_main() – oscillator stays off until hv_control_task()
     * enables it after the startup delay.
     */

    /* Software regulation: initialise ADC and mutex.
    s_mutex = xSemaphoreCreateMutex();
    if (!s_mutex) return ESP_ERR_NO_MEM;
    esp_err_t ret = adc_init();
    if (ret != ESP_OK) return ret;
    */

    ESP_LOGI(TAG, "initialized (hardware regulation mode)");
    return ESP_OK;
}

float hv_control_get_voltage(void)
{
    /* Software regulation: return measured voltage.
    xSemaphoreTake(s_mutex, portMAX_DELAY);
    float v = s_voltage;
    xSemaphoreGive(s_mutex);
    return v;
    */
    return 0.0f;   /* not measured in hardware-regulation mode */
}

/* ── Task ─────────────────────────────────────────────────────────────── */

void hv_control_task(void *arg)
{
    (void)arg;

    /* Startup delay – let the rest of the system settle before enabling HV */
    vTaskDelay(pdMS_TO_TICKS(500));

    hv_control_enable();

    /* ── Software regulation loop (disabled) ──────────────────────────── */
    /*
    const TickType_t period = pdMS_TO_TICKS(HV_REGULATION_PERIOD_MS);
    TickType_t last_wake    = xTaskGetTickCount();

    while (1) {
        vTaskDelayUntil(&last_wake, period);

        float vhigh = adc_read_vhigh();

        xSemaphoreTake(s_mutex, portMAX_DELAY);
        s_voltage = vhigh;
        xSemaphoreGive(s_mutex);

        if (vhigh < (HV_TARGET_VOLTAGE_V - HV_HYSTERESIS_V)) {
            if (!s_hv_on) {
                hv_control_enable();
                ESP_LOGI(TAG, "HV low (%.1fV) – oscillator ON", vhigh);
            }
        } else if (vhigh > (HV_TARGET_VOLTAGE_V + HV_HYSTERESIS_V)) {
            if (s_hv_on) {
                hv_control_disable();
                ESP_LOGI(TAG, "HV high (%.1fV) – oscillator OFF", vhigh);
            }
        }
    }
    */

    /* Hardware regulation active – nothing more to do */
    vTaskDelete(NULL);
}
